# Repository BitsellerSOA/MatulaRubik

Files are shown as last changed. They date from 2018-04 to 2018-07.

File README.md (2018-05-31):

# MatulaRubik
Proyecto SOA UNLAM 2018 1 C Martes Noche

### Colaboradores
- [Radice Adrian](https://github.com/adrianRadice)
- [Sanabria Facundo](https://github.com/FockaSanabria)

### Introduccion
El proyecto es una implementación de IOT, el mismo consiste en un SE que tendrá el fin de resolver el cubo rubik. 

### Objetivo
Resolver el cubo rubik, mediante un sistema automático.

### Limite
Desde que el cubo es analizado por la App Movil y el SE devuelve el cubo resuelto como fue indicado por la APP.

### Alcance
- La App Android `MatulaRubik` analizara el cubo, capturando la posición de los colores con el uso de la libreria OpenCV 3.4.1, y entregara en un repositorio web la solución a ser tratada por el SE.
- La App Android `MatulaRubik` registra un historial de logros ( Tiempos previos logrados ) y configuración del Cubo.
- El sketch de Arduino retirara la solución entregada por `MatulaRubik` del repositorio WEB.
- El sketch de Arduino interpretará  la solución  del cubo y la traducirá  en los movimientos mecánicos.

### Dedicación
Este proyecto es una dedicación especial a nuestro hermano perdido en acción. Matias por siempre presente en Bitseller.
<p align="center">
  
  
  
</p>

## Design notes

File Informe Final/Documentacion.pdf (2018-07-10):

# MatulaRubik

Nombre y Apellido Radice Adrián – Sanabria Facundo Asignatura Sistemas Operativos Avanzado – Docentes: Lic. De Luca Graciela – Ing. García Gerardo – Ing. Valente Waldo – Ing. Carnuccio Esteban.
Universidad Nacional de La Matanza – Departamento de Ingeniería e Investigaciones Tecnológicas (http://ingenieria.unlam.edu.ar/index.php?seccion=4)

radiceadriann@gmail.com - facundosanabria@gmail.com

Kerwords IOT – Rubik – Arduino – Ethernet – Android – JSON – Post – Steeper – Driver – Puente H – DRV8825 – L293 – NDK – OpenCV.

Abstract- El objetivo del presente trabajo es desarrollar
un sistema de IOT, donde se demuestra el conocimiento adquirido en la cátedra de sistemas operativos avanzados. El propósito del sistema es Resolver el conocido juego de lógica Cubo Rubik 3x3x3, automáticamente.
Podrán tener acceso al código y detalles de construcción en el repositorio [github.com/BitsellerSOA/MatulaRubik].
I. INTRODUCCIÓN

El presente trabajo es una implementación de IOT, el mismo consiste en un SE que tendrá el fin de resolver el cubo Rubik de 3x3x3. El cubo Rubik es un juego que combina lógica con movimientos mecánicos. Existen diversos algoritmos para resolverlo. El elegido en el presente trabajo es el algoritmo CFOP (Cross – F2L – OLL – PLL) o también conocido por el nombre de su autor Fridrich. El algoritmo será aplicado por un equipo celular con Sistema Operativo Android, el cual entregará la secuencia de movimientos a aplicar por la parte mecánica del sistema controlada por un Arduino Mega 2560.

II. OBJETIVO

Resolver el cubo Rubik 3x3x3, mediante un sistema automático implementando IOT.

III. LIMITE

Desde que el cubo Rubik de 3x3x3 es analizado por la App Móvil y el SE devuelve el cubo resuelto como fue indicado por la APP.

IV. ALCANCE

- La App Android MatulaRubik analizara el cubo, capturando la posición de los colores con el uso de la librería OpenCV 3.4.1, y entregara en un repositorio web la solución a ser tratada por el SE.
- La App Android MatulaRubik registra un historial de logros (Tiempos previos logrados) y configuración del Cubo.
- El sketch de Arduino retirara la solución entregada por MatulaRubik del repositorio WEB.
- El sketch de Arduino interpretará la solución del cubo y la traducirá en los movimientos mecánicos.
- El sistema embebido ante desconexión, o reseteo volverá al estado de reposo, no necesariamente informando a la app.
V. SOFTWARE UTILIZADO
- Android Studio. Para el desarrollo de la app Android.
- Arduino IDE 1.8.5. Para el desarrollo del sketch Arduino.
- Enterprise Architect. Para diagramas y documentación.
- Git. Para el control de versiones del código.
- Fritzing. Para Los diagramas de circuitos.
VI. | HARDWARE UTILIZADO
ELECTRONICA | CANTIDAD
Arduino Mega 2560 | 1
Capacitor 1000uf | 1
Capacitor 100uf | 3
DRV 8825 | 3
L293D | 1
Motor DC | 1
Shield W5100 | 1
Stepper | 3
Fin de carrera | 1
Resistencia
OTROS | CANTIDAD
Cable
Perfboard | 1
Zocalos | 1
VII. | MATERIALES UTILIZADOS
VIII. | HERRAMIENTAS UTILIZADAS
- Soldador.
- Taladro.
- Mecha Madera y Metal
- Destornillador.
- Multímetro.
- Alicate.

IX. DETALLES COMPONENTES

ARDUINO MEGA 2560

Objetivo en el proyecto: Se encargará de efectuar los movimientos mecánicos que implican resolver el Puzzle.

MATERIAL | CANTIDAD | DIMENSION
Acrílico | -
Aluminio | -
Varilla Enroscada | 4
Chapa Galvanizada | -
Estaño | -
Madera | -
Pegamento | -
Tornillo (Pinzas) | 3
Tornillo (Sujeta retroceso) | 4
Tornillo (Sujeta Steeper) | 12
Tuerca | 16

Características:

CARACTERISTICAS ELECTRICAS
Microcontrolador | ATmega 2560
Tensión de operación | 5V
Tensión de alimentación | 6-20V recomendado 7-12V
Pines digitales | 54 (15 proveen salida PWM)
Pines Analógicos | 16
Corriente por Pin I/O | 20mA
Corriente Pin salida 3.3V | 50mA
Memoria Flash | 256KB – 8KB Bootloader
Clock | 16 MHz
DIMENSIONES
Largo | 101.52 mm
Ancho | 53.3 mm

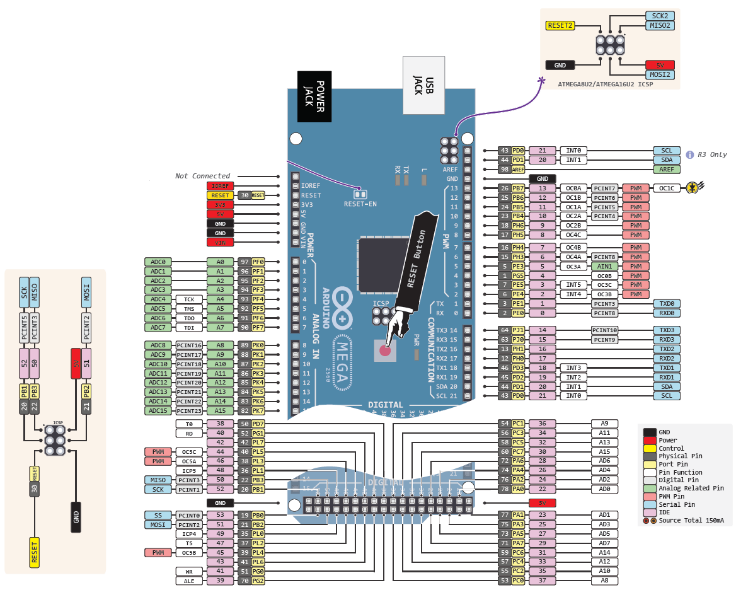
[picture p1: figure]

Fig. 1. Mapa de pines Arduino.

SHIELD W5100

Objetivo en el proyecto: permite la comunicación entre el Arduino y el celular. No se usa del shield las prestaciones para SD.

Pin Arduino: 50 – 51 – 52 – 53 para la comunicación SPI.

Características

- Tensión de alimentación: utiliza 5V suministrados por el Arduino.
- Buffer interno de 16k.
- Permite comunicaciones 10/100Mb.
- Indicadores Led
- TX
- RX
- LINK
- 100M
- ON

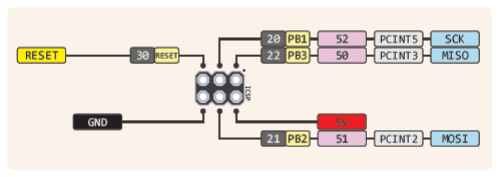
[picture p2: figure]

Fig. 2. Diagrama que indica que los pines del 50-53 están imposibilitados para su uso.

FIN DE CARRERA

Objetivo en el proyecto: indicar cuando el motor DC alcanzo la posición deseada.

Configuración: NC con resistencia Pull Down.

Señal: Digital.

Estados: High cerrado, Low Abierto. Por configuración NC.

Pin Arduino: Pin 22 configurado como entrada.

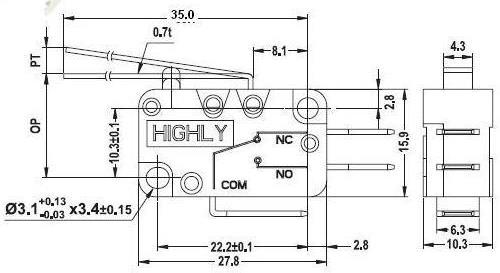
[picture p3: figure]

Fig. 3. Diagrama físico del sensor fin de carrera.

Iteración con Arduino: Para simplificar su descripción utilizaremos el autómata descripto en la Fig 1.

- El estado 1 implica el Motor DC en reposo.
- El estado 2 indica el motor DC excitado.
- La transición q1 se da cuando el Arduino interactúa con el puente H y este polariza el motor DC para que empiece a moverse.
- La transición q3 implica la lectura Low en el pin digital en el que está conectado el fin de carrera.
- La transición q2 implica la lectura HIGH en el pin digital en el que está conectado el fin de carrera.

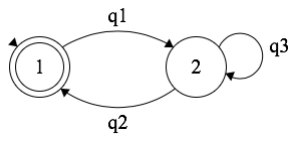
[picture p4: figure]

Fig. 4. Máquina de estados iteración Arduino fin de carrera.

Iteración Mecánica: Dado que existen retardos para pasar del estado 2 al 1, la chapa del fin de carrera respecto a la posición deseada se separa una distancia D Fig 1. Los retardos incluyen desde que se recibe el nivel alto en el Arduino, este envía la orden de detención, el DC se detiene y se compensa el empuje.

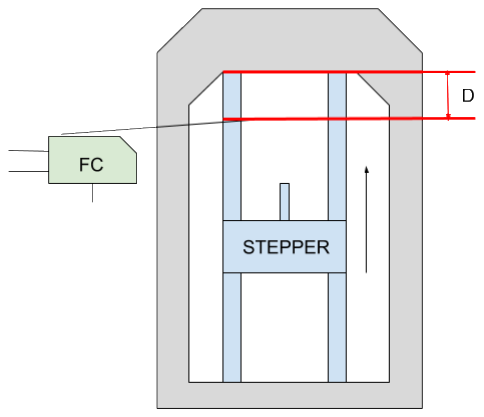
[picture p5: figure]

Fig. 5. Representación física de la iteración. No está a escala.

RESISTENCIA

Objetivo en el proyecto: Completar circuito para el Fin de carrera. La misma permite que no se produzca un corto al cerrarse el circuito.

Valor: 10kΩ

Estados: High cerrado, Low Abierto. Por configuración NC.

Fig. 6. Diagrama lógico de configuración pull down.

CAPACITOR

Objetivo en el proyecto: Proteger a los DRV8825 que son muy sensibles a picos de tensión. Estas variaciones de tensión principalmente aparecen cuando los motores actúan.

Tipo: Electrolítico.

Valores: el fabricante del drv8825 recomienda capacitores con un valor mínimo de 47uf, dado a nuestra disponibilidad usamos de 100uf.

PERFBOARD

Objetivo en el proyecto: permite el montaje de los circuitos comentados en FIG 15. La perfboard es una placa de circuito perforada cuyos huecos están circundados por material conductor, usualmente cobre, pero que no están interconectados entre sí. Este tipo de placas requieren que cada componente esté soldado a la placa y además las interconexiones entre ellos sea realizada a través de cables o caminos de soldadura.

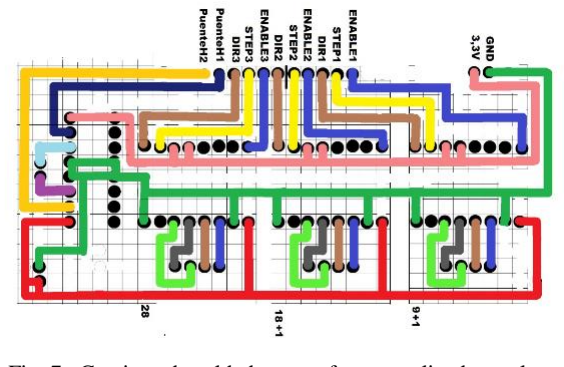
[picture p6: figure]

Fig. 7. Caminos de soldadura que fueron realizados en la perfboard.

CABLE SIMPLE

Objetivo en el proyecto: conductores eléctricos. Se utilizan para interconectar los motores al driver, y en la alimentación del sistema embebido.

1 Para el proyecto no es necesario un puente H doble, se utilizó el L293D porque ya se lo poseía.

CABLE ETHERNET

Objetivo en el proyecto: Permite la conexión del SE a una Red.

Características: UTP CAT 5e Norma T568, Cruzado.

MOTOR DC

Objetivo en el proyecto: el retroceso y avance del brazo que mueve la cara lateral.

Características: Tención de alimentación 9V.

Sentido de giro: Controlado por el puente HL293D.

PUENTE H L293D¹

Objetivo en el proyecto: Control de giro del Motor DC que desplaza el brazo lateral.

Características:

CARACTERISTICAS ELECTRICAS
Tensión lógica | 5V
Tensión de salida (Usada) | 9V
Corriente de salida | 600 mA
Admite PWM | SI

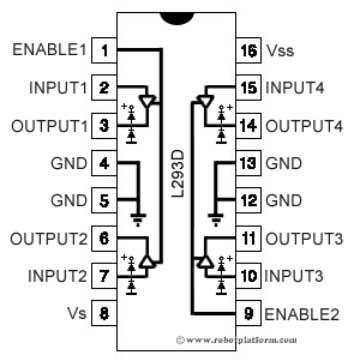
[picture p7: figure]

Fig. 8. Pines Integrado L293D

Pin Arduino: Pin 38 y 39 configurado como salida.

Iteración con Arduino:

ENABLE | INPUT 1 | INPUT 2 | Motor
LOW | HIGH/LOW | HIGH/LOW | PARADO
HIGH | HIHG | LOW | MOV 1
HIGH | LOW | HIGH | MOV 2

Tab. 1. En el proyecto solo se trabaja con las dos últimas filas. Mov 1 y Mov 2 representaran en el proyecto un movimiento de izq a derecha o de derecha a izquierda.

MOTOR STEPPER BIPOLAR

Objetivo en el proyecto: se encarga de rotar las caras del cubo con pasos de π/2 y múltiplos del mismo.

Características:

CARACTERISTICAS ELECTRICAS
Step Angle | 1.8 deg (200 pas por vuelta)
Tensión | 4,83 V
Corriente | 0.84 A
Torque | 2.8 Kg/cm

Movimiento: Controlado por el DRV8825.

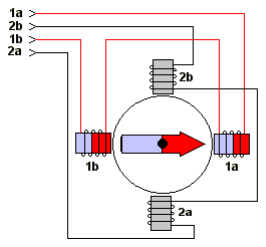
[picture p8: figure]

Fig. 9. Esquema de un motor bipolar. Se denominan bipolares porque de acuerdo al sentido de la corriente se forma un campo magnético S/N o N/S.

Fig. 10. Dimensiones físicas del motor utilizado.

DRV8825

Objetivo en el proyecto: Control de los motores paso a paso del circuito. En sencillas palabras actúan como una válvula que separa la corriente que alimenta al Arduino de la que es necesario hacer circular por el motor. Este driver particularmente esta compuesto por dos puente H que utiliza para cambiar la dirección de la corriente en las bobinas del motor bipolar que controla.

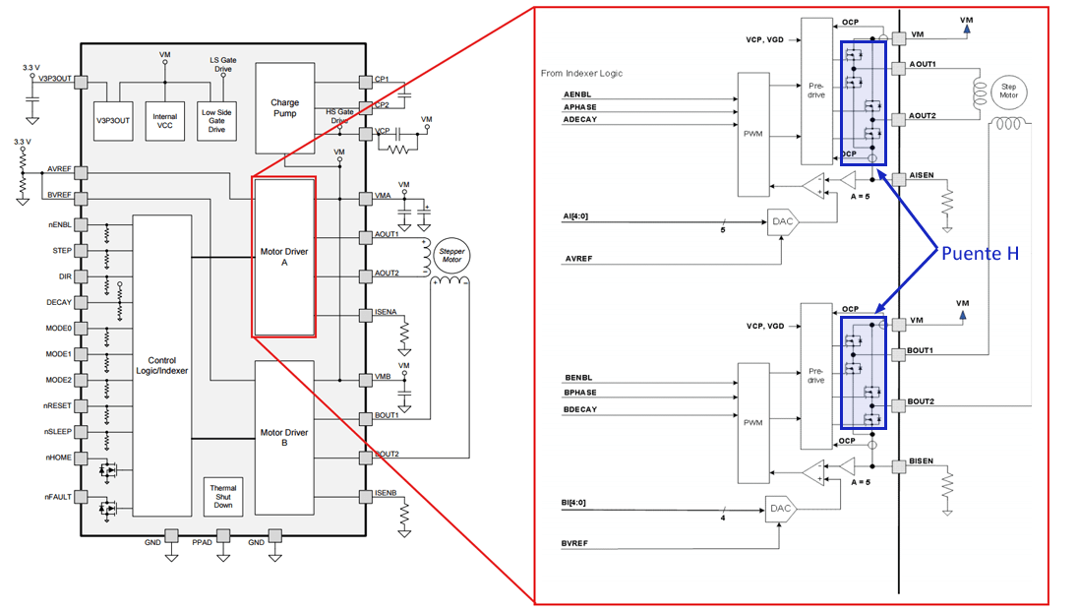
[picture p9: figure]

Fig. 11. Composición del DRV8825.

Características:

CARACTERISTICAS ELECTRICAS
Intensidad máxima | 2.5A a 24V
Tensión máxima | 8.2V a 45V
Tensión de pines lógicos de entrada | 2.25V a 5.5V

Pin Arduino: Pines 24, 28, 33 para enable, 25,30 y 34 para step y 26, 31 y 36 para dirección.

Iteración con Arduino:

El Arduino envía el pulso (STEP). Cada pulso le dice al motor que tiene que avanzar un paso. Otro pin nos dice la dirección de avance (DIR). Si queremos ir en el sentido de las agujas del reloj, o al contrario. De esta forma, cada vez que el driver recibe un pulso en el pin STEP, el circuito comprueba el voltaje del pin DIR, y alimenta las bobinas del motor en el orden adecuado.

Fig. 12. Señal enviadas al Driver.

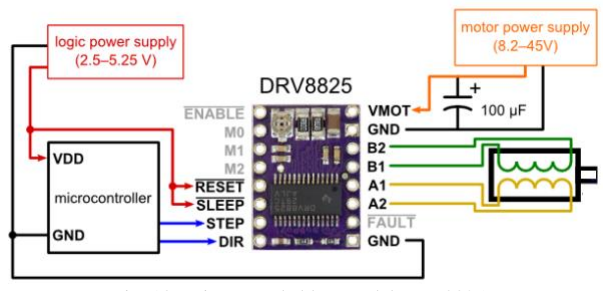
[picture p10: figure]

Fig. 13. Diagrama de bloques del DRV8825.

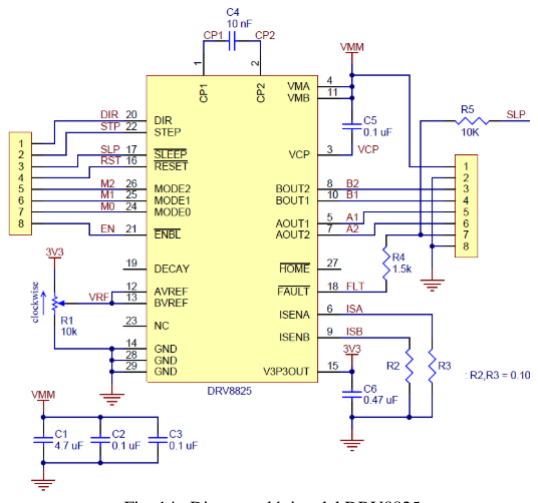
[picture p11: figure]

Fig. 14. Diagrama lógico del DRV8825

X. CIRCUITOS

CIRCUITO PARA CONTROL DE MOTOR STEPPER.

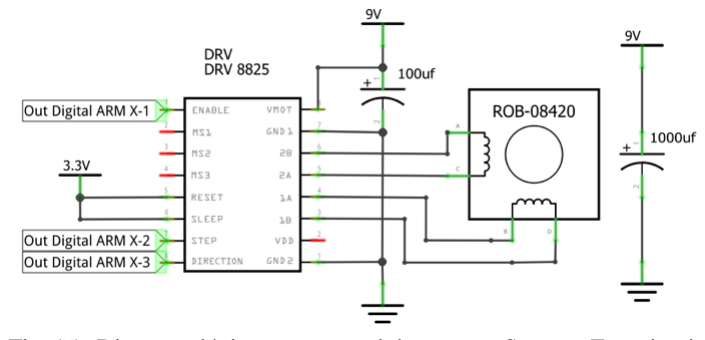
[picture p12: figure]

Fig. 15. Diagrama lógico para control de motores Stepper. Este circuito se implementa 3 veces para controlar cada uno de los motores. El circuito completo podrá ser consultado al final de este documento.

Etiqueta | Pin Arduino
MOTOR U
X-1 | 24
X-2 | 25
X-3 | 26
MOTOR D
X-1 | 28
X-2 | 30
X-3 | 31
MOTOR L
X-1 | 33
X-2 | 35
X-3 | 36

BREVE EXPLICACIÓN DEL CIRCUITO:

El objetivo de este circuito es el control de un motor paso a paso, por lo tanto, tendremos 3 en total. Los motores pasos a paso tienen como objetivo principal efectuar los movimientos sobre las caras del cubo. Los movimientos a efectuar son giros de 90 grados en sentido horario/antihorario o múltiplos del mismo. El DRV será el intermediario entre el paso a paso y el Arduino. El capacitor de 100uf observador en la figura fue recomendado por el fabricante como fue especificado en el apartado Detalles de componentes Capacitor.

CIRCUITO PARA CONTROL DE MOTOR DC.

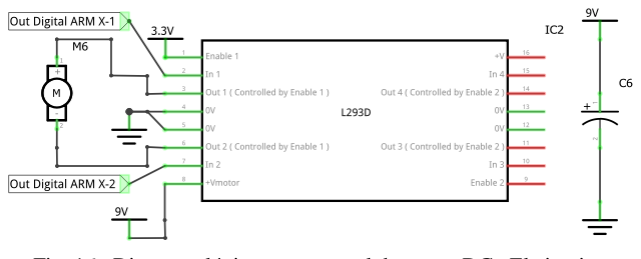
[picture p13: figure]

Fig. 16. Diagrama lógico para control de motor DC. El circuito completo podrá ser consultado al final de este documento.

Etiqueta | Pin Arduino
MOTOR DC
X-1 | 52
X-2 | 53

BREVE EXPLICACIÓN DEL CIRCUITO:

El objetivo de este circuito es permitir un desplazamiento horizontal de uno de los brazos. Un movimiento horizontal puede ser de izquierda a derecha o de derecha a izquierda. Para lograr dicho movimiento, si el objeto que queremos mover interactúa con un tornillo sin fin, bastaría con cambiar el sentido de giro de un motor. El motor que interactúa en esta parte del circuito es un DC convencional, por lo tanto, su sentido de giro queda determinado por cómo es polarizado. Para paralizar de dos formas distintas al motor utilizamos un puente H, en este caso uno de los dos que provee el L293D. Los 3.3v que son utilizados para habilitar el L293D serán suministrados por el Arduino. Los 9v empleados para alimentar el motor DC serán suministrados por la fuente externa que alimenta a todo el proyecto. X-1 y X-2 enviaran los pulsos necesarios para lograr la codificación digital (Tab. 1) que requiere el puente H.

XI. CONSTRUCCIÓN MECÁNICA

MAQUINA:

PONER UNA FOTO CON LA ESTRUCTURA ARMADA Y PONER CON PAINT UNA ETIQUETA SOBRE LOS MOTORES E INDICAR QUE CARAS MUEVEN CADA UNO, Y PUNTO.

Motores | Movimiento
MS-U | U
MS-D | D
MS-L | { F, L , R , B }
M-DC | RETROCESO M-L
{U, D, F, L, R, B} Son las caras del cubo Rubik, en introducción sobre CFOP se explica la nomenclatura.

PINZAS:

Para sujetar las pinzas a los ejes del motor paso a paso, se utilizó el concepto de las borneras.

Fig. 16. En azul se simboliza al tornillo que presionara el borde plano del eje del motor paso a paso.

PINZAS SUPERIOR E INFERIOR:

PINZA LATERAL:

XII. INTRODUCCIÓN A CFOP

Existen muchos algoritmos para poder resolver el cubo Rubik, en este trabajo se eligió a CFOP o también conocido por el nombre de su autor Fridrich. El motivo fue porque era el que conocíamos. El algoritmo como indica en su sigla se compone de 4 etapas Cross, F2L, OLL, PLL.

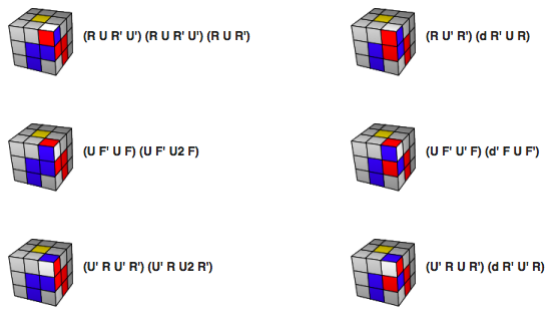
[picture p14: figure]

Fig. 18. Automta que representa las etapas principales del Algoritmo

El algoritmo tiene una nomenclatura especifica la cual fue adoptada para nuestro proyecto con ciertas modificaciones.

CARAS (C)
Superior (Up) | U
Inferior (Down) | D
Trasera (Back) | B
Derecha (Right) | R
Izquierda (Left) | L
FRONTAL (Front) | F
Movimientos
Horario 90* | (C)
Horario 180* | (C)2
Antihorario 90* | (C)’
Antihorario 180* | (C)’2

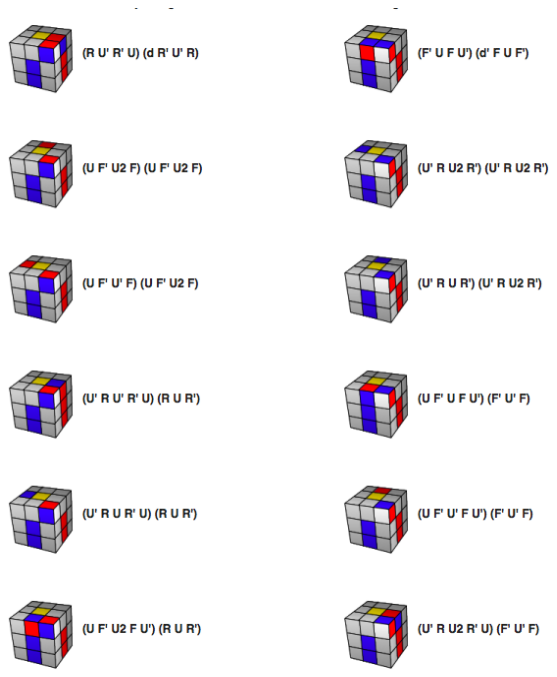
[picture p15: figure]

Fig. 19. Nomenclatura. Notar que en la nomenclatura se emplea un apostrofe para los movimientos antihorarios, que en el código será remplazado por una ‘A’ quedando por ejemplo FA, UA, etc. Se considera sentido horario respecto a mirar la cara de frente. Los movimientos de 180 grados fueron efectuados como dos consecutivos de 90 grados.

Para el desarrollo del paper, consideramos que empezamos armando la cara blanca. A continuación se detalla cada uno de los estados de las distintas etapas, y la secuencia de movimientos que implican cambiar de estado.

CROSS

Objetivo: Armar cruz en la cara de partida.

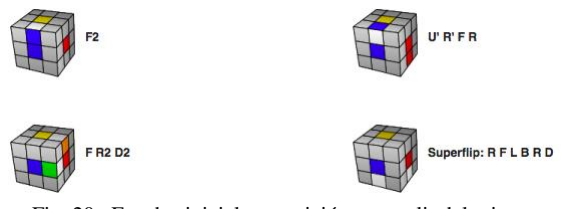
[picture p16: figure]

Fig. 20. Estados inicial y transición para salir del mismo.

F2L FIRST TWO LAYER

Objetivo: Ubicar esquinas de cara inferior, y bordes de cara intermedia. Se pueden dar 41 casos.

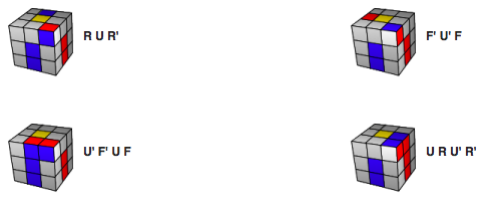
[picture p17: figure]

Fig. 21. Estados inicial y transición para salir del mismo.

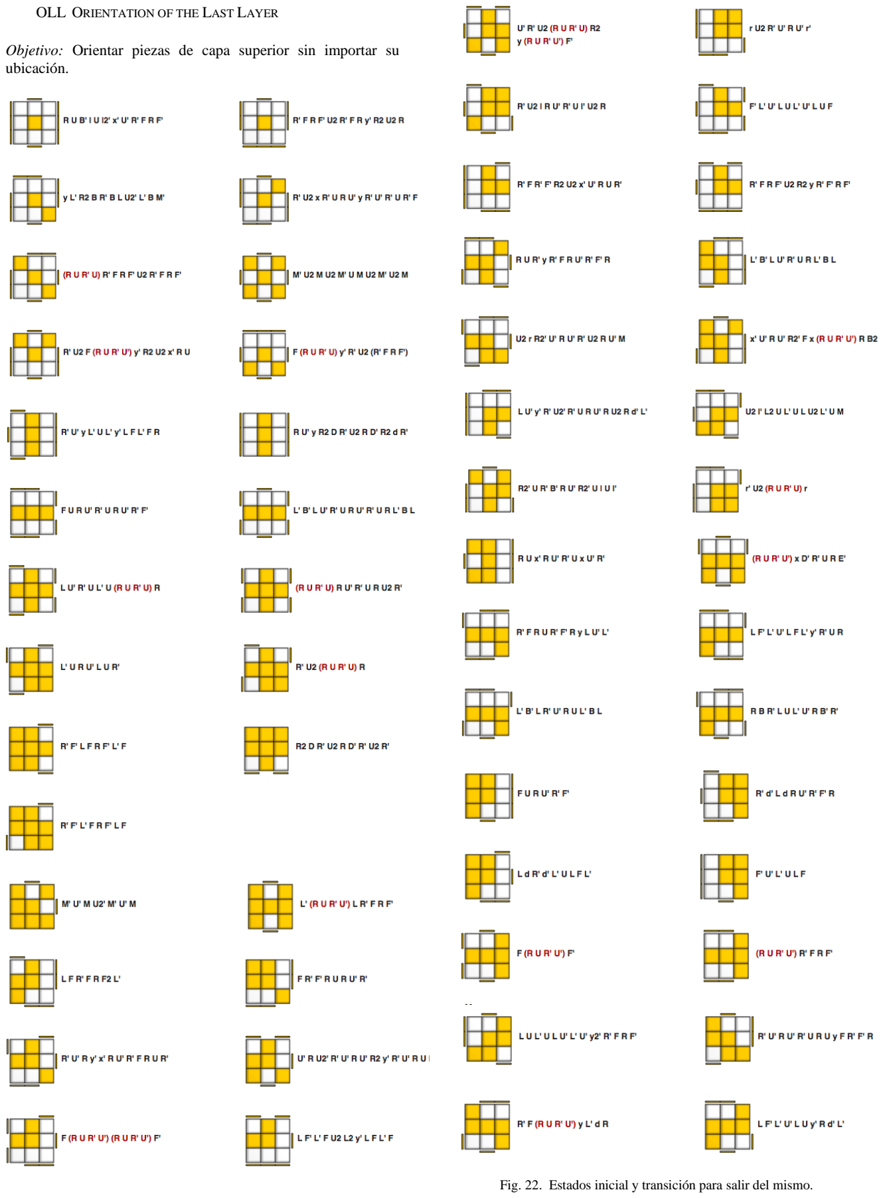
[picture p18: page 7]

OLL ORIENTATION OF THE LAST LAYER

Objetivo: Orientar piezas de capa superior sin importar su ubicación.

Fig. 22. Estados inicial y transición para salir del mismo.

PLL PERMUTATION OF THE LAST LAYER

Objetivo: Ubica en la posición correcta las piezas de la capa superior.

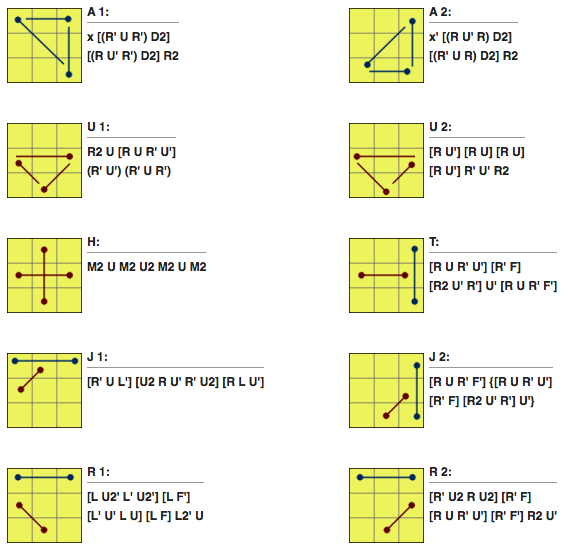
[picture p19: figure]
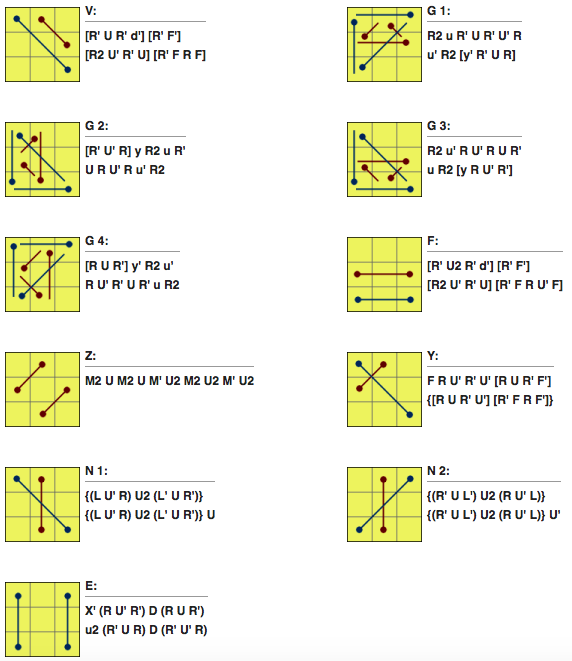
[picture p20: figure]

Fig. 23. Estados inicial y transición para salir del mismo.

ALMACENAMIENTO DEL CUBO

La ubicación de las artistas y esquinas del cubo se almacenan en una matriz de 6*9 del tipo char. Con la siguiente distribución.

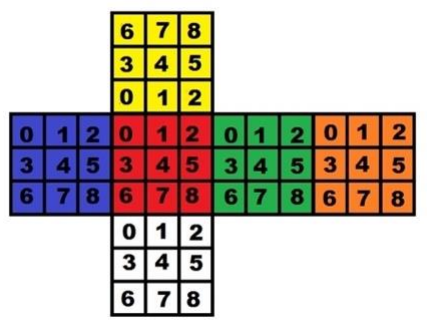
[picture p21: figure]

Fig. 24. Estados inicial y transición para salir del mismo.

XIII. COMUNICACIÓN APP Y ARDUINO

RESUMEN MENSAJES JSON INTERCAMBIADOS

- OK
- ERROR
- DESCONEXION
- SOLUCION LISTA
- COLOCAR CUBO
- {R, L, D, U, B, F, X, Y, Z, V, W, N} REPRESENTAN
MOVIMIENTOS.

PSEUDOCODIGO

1 La App verifica si existe el Arduino.
1.1 La App envía un mensaje a la Dirección IP del Arduino.
1.2. La app Espera respuesta del Arduino por un intervalo de tiempo determinado.
1.3. El Arduino ante la solicitud del celular puede:
1.3.a No responder.
1.3.a.1 Se vence el plazo de tiempo en la app y emite un mensaje que dice Arduino no responde.
1.3.b Estoy Ocupado
1.3.b.1 La app informa el estado del Arduino.
1.3.c Estoy disponible
2 Si La app determina la disponibilidad del Arduino, verifica tener el cubo frente a su cámara.
2.1 Si la respuesta anterior es negativa solicita que se coloque un cubo.
2.2 Si la respuesta anterior es positiva escanea la primera cara. 2.3 La app Envía un post a Arduino indicando que mueva el motor de abajo y superior en sentido horario.
2.4 Arduino ejecuta el movimiento y informa a la app.
2.5 La app escanea la cara.
SE REPITE 3 VECES LA SECUENCIA DEL 2.4 AL 2.5
3 La app notifica que se mueva el motor lateral mediante un post para escanear la cara inf.
3.1 Arduino recibe la solicitud ejecuta la combinación de movimiento motor lateral y luego inferior y superior para que la cara inferior quede frente la cámara
3.1 La app escanea la cara
La app notifica que se mueva el motor inf y sup para que la cara sus quede frente a la cámara
4.1 Arduino recibe la solicitud ejecuta el movimiento
4.2 La app escanea la cara
La app Aplica el algoritmo para resolver, mientras tanto Arduino espera el post de la app indicando la disponibilidad de la solución para poder descargarla y aplicarla.
La app espera que Arduino indique que termino de aplicar la secuencia de movimientos y notifica a la aplicación que finalizo. APARTIR DE PASO 5 NO ES NECESARIO EL CELULAR EN LA BASE DE LA MAQUINA

XIV. DIAGRAMAS APP
- Activity
- Acerca => Información de la aplicación
- Apertura => Splash de bienvenida
- Main => principal
- Clases
- CFOP => Algoritmo de resolución
- ColorDectector => Reúne métodos para detectar lo colores con la cámara.

- Solver => Reúne los métodos para resolver el cubo

XV. REQUISITOS APP

Requisito
OS | > = Android 6.0
Cámara | SI
Uso de Red | SI
Memoria | <COMPLETAR>
XVI. | INTRODUCCIÓN A OPENCV Y NDK

OPENCV es una librería de visión artificial de uso libre, desarrollada en C/C++ lo cual para poder ser utilizada por Android debemos recurrir a la cross compilación ofrecida por NDK. De los módulos ofrecidos por OPENCV emplearemos el CORE ( Incluye las estructuras de datos básicas y las funciones básicas de procesamiento de imágenes) y el OBJDETECT.

Para la detección de colores utilizaremos el concepto de máscaras y el espacio de colores HSV. Cada mascará definirá un rango de valores máximo y mínimo. Tendremos una máscara por color excepto por el rojo que dado a la ubicación del mismo en el campo de HSV requiere dos, porque tiene dos rangos Fig.5.

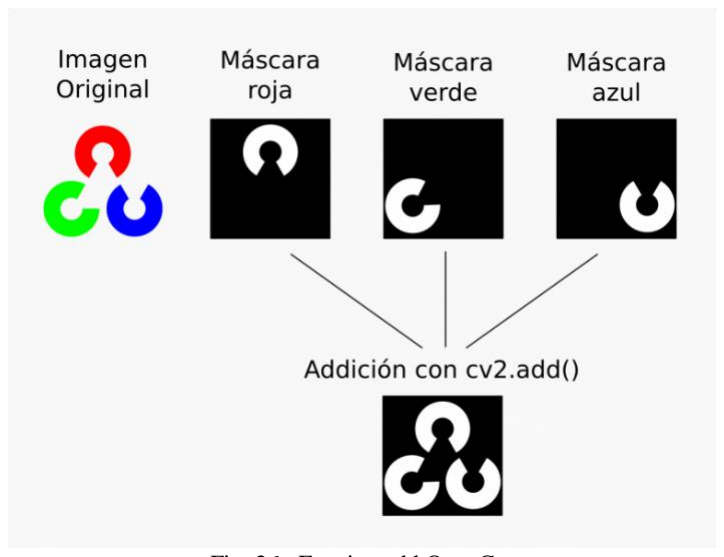
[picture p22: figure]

Fig. 26. Funcion add OpenCv.

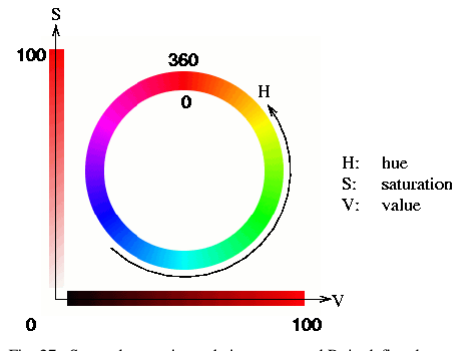
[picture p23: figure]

Fig. 27. Se puede apreciar en la imagen que el Rojo define dos rangos por la componente H, uno del 0 hasta estar próximo al amarillo, y otro desde las fronteras con el violeta hasta el 0.

XVII. IMPLEMENTANDO HPC

Consultar
https://github.com/BitsellerSOA/MatulaRubik/tree/master/TP%20HPC/HPC.pdf

XVIII. PRUEBAS

PRUEBAS ALGORITMO DE RESOLUCIÓN

Dado que son extremadamente grandes (eq.1) todas las configuraciones que se pueden obtener al mezclar el cubo Rubik, sería imposible querer probar que el algoritmo puede resolverlas a todas. Por lo tanto, consideraremos que resolver el cubo seria la integración de muchos métodos, que podrán ser probados unitariamente y luego mediante una prueba de integración podremos afirmar que si logra resolver 10 escenarios distinto el algoritmo será aceptable.

Las pruebas unitarias que deberá enfrentar el algoritmo podrán ser agrupadas en 3 etapas a ejecutar en orden:

- Realiza los movimientos simples correctamente.
- Resuelve correctamente un paso del algoritmo CFOP.
- | Identifica | correctamente | que | secuencia | de
movimientos se debe aplicar.

La primera etapa es fácil de probar, el objetivo es que haga los desplazamientos correctamente en la matriz. Por lo tanto se tendrá una prueba para cada posible movimiento del cubo { U, U’, D, D’, L, L’, R, R’, B, B’, F, F’}. Se partirá siempre del cubo ordenado (matriz Fig. 5) y se comparará con el resultado esperado.

La segunda etapa tiene como objetivo probar a cada una de las secuencias de CFOP. Se entrega la matriz en el estado esperado y luego se compara con la matriz obtenida, para identificar si la secuencia es correcta.

La tercera etapa, probara el método que determina en qué estado se encuentra el cubo, para ello se entrega el cubo desordenado y se compara con el estado esperado.

Superada las tres etapas anteriores consideramos que el algoritmo será óptimo para pasar a la prueba de integración. Donde se entregará 10 configuraciones distintas del cubo con distintos grados de complejidad, y se probará que la matriz quede en el estado de cubo resuelto.

PRUEBAS IDENTIFICACIÓN DE COLORES

Dada las características de esta operación, esta prueba no puede ser automatizada, por lo tanto, se realizará por inspección visual. Se entregan por lo menos 10 distintas configuraciones random del cubo y se observa que los colores sean correctamente identificados por la aplicación. Los colores mostrados por la app deberán coincidir con los reales.

PRUEBAS INSPECCIÓN DE COLORES

Dada las características de esta operación, esta prueba no puede ser automatizada, por lo tanto, se realizará por inspección visual. El objetivo de esta prueba es la correcta sincronización entre la app y el Arduino. Se probará que el intercambio de confirmaciones entre ambos, en donde ni la app deberá inspeccionar colores hasta que Arduino se lo confirme, así como el Arduino no efectué movimientos hasta que la app se lo indique.

PRUEBAS DESCONEXIÓN DURANTE INSPECCIÓN

Dada las características de esta operación, esta prueba no puede ser automatizada, por lo tanto, se realizará por inspección visual. El objetivo de esta prueba es la correcta sincronización entre la app y el Arduino. Ante la pérdida de comunicación entre la app y el Arduino, la app deberá informar por pantalla, y el Arduino quedará en estado de reposo. La pérdida de comunicación se evaluará de la siguiente forma.

- Desconexión del Arduino durante la inspección.
- Reseteo del Arduino durante la inspección.
- Cierre de la app durante la inspección.
- Desconexión del celular de la red.

PRUEBAS MOVIMIENTO ARDUINO

Desconocemos técnicas de pruebas automatizadas para hardware, por lo tanto, usaremos la inspección visual. Se entregará al SE el cubo y se probará cada una de las funciones del sketch que representa un movimiento, si lo aplica correctamente. Las funciones a probar son:

- | u() | • | uA() | • | mover(char c)
- | d() | • | dA()
- | f() | • | fA()
- | r() | • | rA()
- | l() | • | lA()
- | b() | • | bA()

PRUEBAS JSON ARDUINO

Se probará que se realice correctamente el parcing, es decir se envía un paquete desde la app, se la recibe con el Arduino y mediante la impresión por puerto serial se observa si es capaz de obtener el movimiento solicitado, o la orden de continuar o cualquiera de los mensajes que previamente definimos.

XIX. ANEXO CÁLCULOS

Cant config =

8!∗3

8
∗12!∗2

12
12

(eq.1)

XX. AUTORES

Radice AdrianArgentino, estudiante de ingeniería en informática en la Universidad Nacional de La Matanza.
Profesional dedicado a sistemas informaticos. Usr GitHub: adrianRadice

Sanabria FacundoArgentino, estudiante de ingeniería en informática en la Universidad Nacional de La Matanza.
Profesional dedicado a sistemas informaticos. Usr GitHub: FockaSanabria

CIRCUITO GENERAL

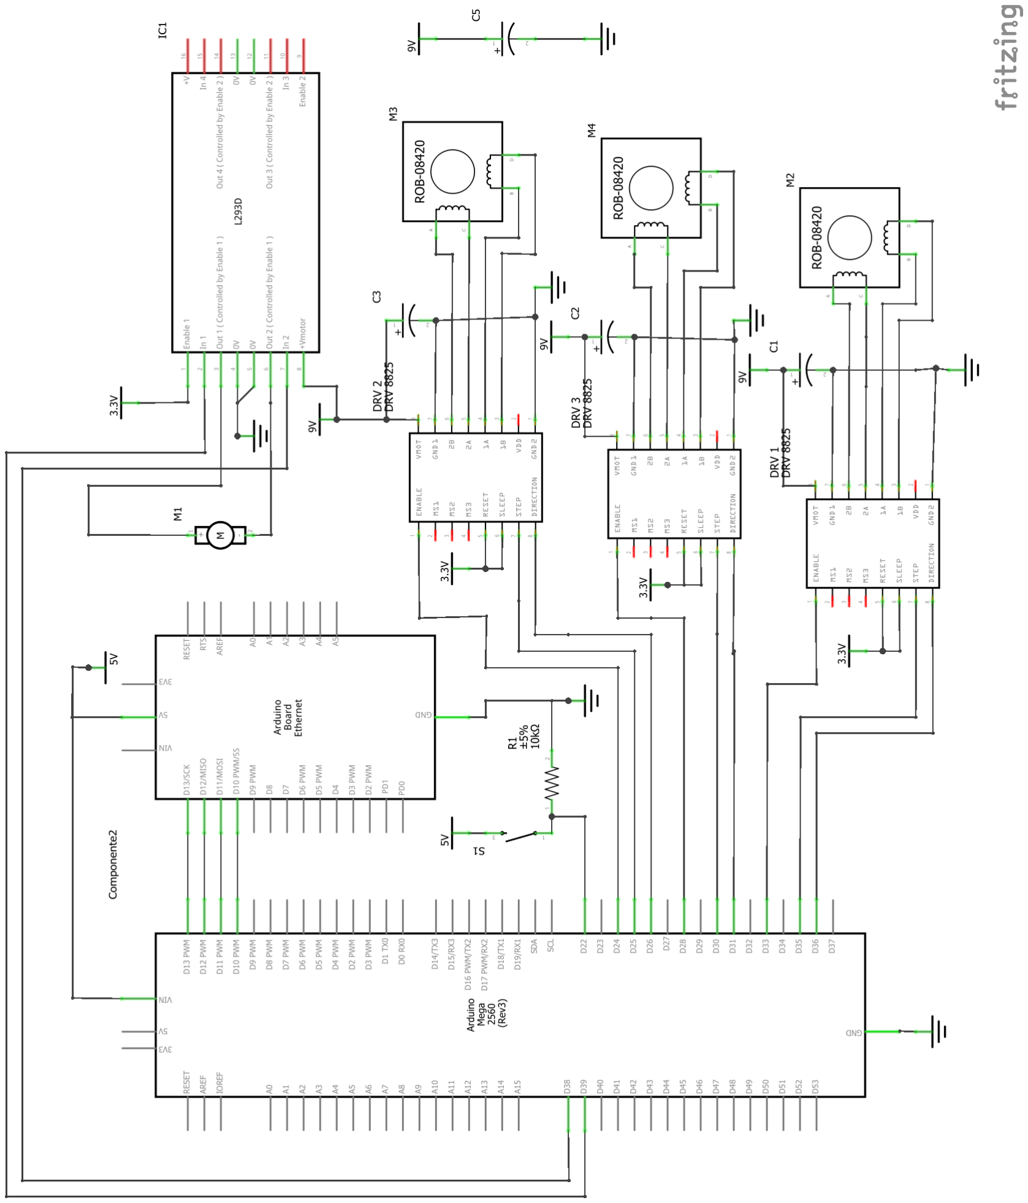
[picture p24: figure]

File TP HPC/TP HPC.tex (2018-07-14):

\documentclass[runningheads,a4paper]{llncs}

\usepackage{amssymb}
\setcounter{tocdepth}{3}
\usepackage{graphicx}

\usepackage{url}

\urldef{\mailsa}\path|{radiceadriann, facundosanabria}@gmail.com|    
\newcommand{\keywords}[1]{\par\addvspace\baselineskip
\noindent\keywordname\enspace\ignorespaces#1}

\newcommand{\MR}{$\emph{MatulaRubik}$ } 

\begin{document}

\mainmatter  % start of an individual contribution

% first the title is needed
\title{Trabajo de Investigación:\\
Integración de HPC en IOT}

% a short form should be given in case it is too long for the running head
\titlerunning{Investigación: HPC y Rubik}

% the name(s) of the author(s) follow(s) next
%
% NB: Chinese authors should write their first names(s) in front of
% their surnames. This ensures that the names appear correctly in
% the running heads and the author index.
%
\author{Adrian Radice%
\and Facundo Sanabria}
%
\authorrunning{Investigación: HPC y Rubik}
% (feature abused for this document to repeat the title also on left hand pages)

% the affiliations are given next; don't give your e-mail address
% unless you accept that it will be published
\institute{Universidad Nacional de La Matanza,\\ Departamento de ingeniería e Investigaciones Tecnológicas,\\
Florencio Varela 1903 - San Justo, Argentina\\
\mailsa\\
\url{http://www.github.com/BitesellerSOA}}

%
% NB: a more complex sample for affiliations and the mapping to the
% corresponding authors can be found in the file "llncs.dem"
% (search for the string "\mainmatter" where a contribution starts).
% "llncs.dem" accompanies the document class "llncs.cls".
%

\toctitle{Lecture Notes in Computer Science}
\tocauthor{Authors' Instructions}
\maketitle

\begin{abstract}
El objetivo del presente trabajo es investigar los beneficios de incorporar HPC en el proyecto de IOT
\MR. Dicho proyecto tiene como desafío resolver un problema NP. Este problema es el puzzle Rubik 3x3x3, el cual
se solucionara implementando el algoritmo no determinístico CFOP. CFOP varia de acuerdo cual 
se su cara de partida, por lo tanto para cualquier cubo se tienen 6 estados iniciales. El desafío es de 6 posibles caminos para 
llegar al estado final, quedarse con aquel que implique el menor uso del brazo lateral.
\keywords{HPC, IOT, Android, Rubik, Paralelismo, OpenCL}
\end{abstract}

\section{Introducción}
\MR es un SE con el objetivo de resolver el Cubo Rubik de 3x3x3, en una primera instancia aplicando el algoritmo utilizado para competencias de velocidad CFOP, el cual obtiene un promedio entre 50 y 100 movimientos para resolver cualquier cubo.
Este algoritmo pertenece a la familia de los llamados \emph{Layer by Layer}, y se caracteriza por llevar a cualquier configuración del cubo a un estado particular, reduciendo siempre 
al problema a la misma solución. En pocas palabras mezcla aun mas el cubo para llevarlo a estados conocidos. 
CFOP es un algoritmo en donde un estado tienen distintas transiciones que nos llevan al estado final, siendo 
cada una finalmente un camino con distinta o igual cantidad de movimientos. 

El objetivo de esta investigación, es reducir el tiempo en que \MR  entrega la solución. \MR  actualmente en su mecánica, 
tiene un retardo extra, la ubicación de las caras laterales en el correspondiente brazo para poder rotarlas. Se buscara mediante
la implementación de HPC con OpenCL, encontrar la solución que reduce el retardo previamente descrito.

\section{Desarrollo}

Estudiando la mecánica de \MR se aprecia que el efectuar movimientos en las caras L, F, R, B pueden sumar un retardo, que no existe nunca al trabajarse con las caras U y D. Por ejemplo la secuencia de movimientos F, B' implica, que luego de ejecutarse el primer movimiento, se sume un retardo temporal hasta que la cara B del cubo quede frente al brazo. Este retardo es el tiempo que implica retirar el brazo lateral, rotar el cubo hasta que B quede frente del brazo, y que el brazo lateral se ubique nuevamente en la posición de trabajo.

Enfrentar dicho problema implicaría dos caminos,  cambiar la mecánica, o buscar una reducción en los movimientos de las caras problemáticas. En el desarrollo del trabajo optaremos por el segundo camino.

\MR en su estado actual aplica el algoritmo CFOP, el mismo presenta la particularidad que para una misma configuración del cubo de acuerdo a la cara que se tome como punto de partida devolverá una secuencia de movimientos totalmente distinto. Es decir, es como si se rotase lógicamente el cubo respecto de uno de sus ejes, lo que provoca que todas las piezas cambien de posición y orientación, resultando en un estado desordenado distinto y por lo tanto el algoritmo devolverá un conjunto de movimientos completamente distinto.

Para lograr obtener la menor cantidad de movimientos posibles utilizando este algoritmo nos proponemos a ejecutar en forma paralela 6 hilos de CFOP, un hilo por cara del cubo.

En busca de no tener que modificar demasiado el código actualmente implementado, se busco una herramienta que implique una implementación sencilla y optima de paralelismo. La herramienta seleccionada fue Paralldroid.

Paralldroid es un framework de desarrollo, que tiene como objetivo facilitar el trabajo de los desarrolladores de aplicaciones móviles ejecutadas sobre sistemas operativos Android, de acuerdo a lo mencionado en "Performance Analysis of Paralldroid Generated Programs" \cite{jour}. El mismo añade un conjunto de anotaciones al lenguaje Java, basadas en las definidas por el estándar OpenCL, permitiendo al desarrollador usar un lenguaje de alto nivel, sin entrar en detalle de implementación de paralelismo, y delegandole la responsabilidad a Paralldroid de generar el programa paralelo, segun lo indicado en "ParallDroid: A Framework for Parallelism in Android" \cite{bookParalldroid}.
Paralldroid puede ser descargado como plugin para eclipse, y solo es necesario instalarlo para que comience a funcionar\cite{jour}.

\begin{figure}
\centering
        
        \caption{Resultado de la refactorización \cite{OpenCLbook}.}
\end{figure}

Como se puede apreciar en la Figura 1 este framework, mediante el código Java con anotaciones, obtendrá un código nativo OpenCL, invocado desde nuestras clases. Es elemental el uso de NDK en cualquier App para poder hacer uso de este framework.

\section{Distribución de operaciones}
La particularidad de los hilos de trabajos propuestos, es que son independíentes entre si, cada uno trabaja con su propia matriz de estado del cubo, sin intervenir con los otros. Partiendo de que el resultado de ParallDroid es una implementación de OpenCL \cite{jour}, cada hilo tendrá destinado un WorkGroup independíente. La primera ventaja de esta división, es que cada WorkGroup podrá ser ejecutado en una unidad de procesamiento distinta, si OpenCL lo considera \cite{OpenCLbook}, y como segunda ventaja es el escalado automático (asignación de WorkGroup a las unidades de procesamiento) que implementa OpenCL \cite{OpenCLbook}. Esta ultima ventaja hace referencia, a que un mismo código, en un dispositivo de mayor cantidad de unidades de procesamiento que WorkGroups, en el mejor de los casos cada  se asignara un WorkGroup por unidad de procesamiento, y en un dispositivo de menor cantidad,  OpenCL simplemente terminaría ejecutando un conjunto de los WorkGroups en serie, en las unidades de procesamiento disponible.

\section{Explicación Algoritmo}

Nos basamos en el típico ejemplo de paralelismo del producto entre un escalar y un vector. Buscar 6 soluciones es isomórfico a esto 
ultimo, si entendemos al resultado de la operación como un conjunto de 6 elementos. 

\medskip
\noindent
{\it Pseudocódigo}
\begin{verbatim}
@Parallel
public class SolverHPC_CFOP {
  private caras[];
  private  Solucion[];
 @Kernel
  private void Solver(CaraInicial){
         //CALCULAMOS LA SOLUCION
         Solucion [CaraInicial] <- CFOP(caraInicial);
  }
  private Solucion getBest(){
 	//SE CALCULA LA MEJOR SOLUCION
 	return Solucion[bestSol];
  }
}
public class Solver{
   SendSol(){
   	SendArduino(SolverHPC_CFOP.getBest());
   }
}
\end{verbatim}
%
\noindent

Según lo mencionado en "Performance Analysis of Paralldroid Generated Programs" \cite{jour}, ParallelDroid al refactorizar el código, agregaría el manejo de hilos, y nos abstrae de su desarrollo.

\section{Pruebas que pueden realizarse}
Para probar el rendimiento se propone, el desarrollo de un programa probador que mida el tiempo que le implica resolver 50 estados desordenados distintos del  puzzle a a MatulaRubik con HPC y luego sin HPC. A partir de estos resultados debería realizarse el promedio para ambos casos y comparar cual obtiene el mejor tiempo.

También seria útil comprobar que el conjunto de movimientos resultados sean distintos dependiendo por que cara se comienza y si difieren mucho entre ellos.

\section{Conclusión}

La fortaleza de la solución propuesta en la investigación, es que permite una implementación de paralelismo sin demasiado esfuerzo de desarrollo. Se aprovecha el poder computacional provisto por el Hardware de los dispositivos móviles, para contrarrestar una deficiencia mecánica. 

Extender la propuesta a cada uno de los distintos estados de CFOP en lugar de solamente los 6 iniciales seria computacionalmente intratable dado que CFOP es un algoritmo no determinístico, con una excesiva cantidad de estados posibles. Se compensaría los retrasos impuestos por la mecánica, con el tiempo de la búsqueda de mejor solución. 

\begin{thebibliography}{4}
\bibitem{jour} A. Acosta and F. Almeida, "Performance Analysis of Paralldroid Generated Programs" 2014 22nd Euromicro International Conference on Parallel, Distributed, and Network-Based Processing, Torino, 2014, pp. 60-67.
\bibitem{bookParalldroid} Vicente Blanco, "ParallDroid: A Framework for Parallelism in Android".
\bibitem{OpenCLbook} Aaftab Munshi, "The OpenCL Specification" Khronos OpenCL Working Group, Revision 2015.
 \end{thebibliography}
\end{document}

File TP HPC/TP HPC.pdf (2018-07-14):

## Trabajo de Investigación: Integración de HPC en IOT

Adrian Radice and Facundo Sanabria

Universidad Nacional de La Matanza, Departamento de ingeniería e Investigaciones Tecnológicas, Florencio Varela 1903 - San Justo, Argentina {radiceadriann,facundosanabria}@gmail.com http://www.github.com/BitesellerSOA

Abstract. El objetivo del presente trabajo es investigar los beneficios de incorporar HPC en el proyecto de IOT MatulaRubik . Dicho proyecto tiene como desafío resolver un problema NP. Este problema es el puzzle Rubik 3x3x3, el cual se solucionara implementando el algoritmo no determinístico CFOP. CFOP varia de acuerdo cual se su cara de partida, por lo tanto para cualquier cubo se tienen 6 estados iniciales. El desafío es de 6 posibles caminos para llegar al estado final, quedarse con aquel que implique el menor uso del brazo lateral.

Keywords: HPC, IOT, Android, Rubik, Paralelismo, OpenCL

### 1 Introducción

MatulaRubik es un SE con el objetivo de resolver el Cubo Rubik de 3x3x3, en una primera instancia aplicando el algoritmo utilizado para competencias de velocidad CFOP, el cual obtiene un promedio entre 50 y 100 movimientos para resolver cualquier cubo. Este algoritmo pertenece a la familia de los llamados Layer by Layer, y se caracteriza por llevar a cualquier configuración del cubo a un estado particular, reduciendo siempre al problema a la misma solución. En pocas palabras mezcla aun mas el cubo para llevarlo a estados conocidos. CFOP es un algoritmo en donde un estado tienen distintas transiciones que nos llevan al estado final, siendo cada una finalmente un camino con distinta o igual cantidad de movimientos.
El objetivo de esta investigación, es reducir el tiempo en que MatulaRubik entrega la solución. MatulaRubik actualmente en su mecánica, tiene un retardo extra, la ubicación de las caras laterales en el correspondiente brazo para poder rotarlas. Se buscara mediante la implementación de HPC con OpenCL, encontrar la solución que reduce el retardo previamente descrito.

### 2 Desarrollo

Estudiando la mecánica de MatulaRubik se aprecia que el efectuar movimientos en las caras L, F, R, B pueden sumar un retardo, que no existe nunca al trabajarse

2 | Investigación: HPC y Rubik

con las caras U y D. Por ejemplo la secuencia de movimientos F, B’ implica, que luego de ejecutarse el primer movimiento, se sume un retardo temporal hasta que la cara B del cubo quede frente al brazo. Este retardo es el tiempo que implica retirar el brazo lateral, rotar el cubo hasta que B quede frente del brazo, y que el brazo lateral se ubique nuevamente en la posición de trabajo.
Enfrentar dicho problema implicaría dos caminos, cambiar la mecánica, o buscar una reducción en los movimientos de las caras problemáticas. En el desarrollo del trabajo optaremos por el segundo camino.
MatulaRubik en su estado actual aplica el algoritmo CFOP, el mismo presenta la particularidad que para una misma configuración del cubo de acuerdo a la cara que se tome como punto de partida devolverá una secuencia de movimientos totalmente distinto. Es decir, es como si se rotase lógicamente el cubo respecto de uno de sus ejes, lo que provoca que todas las piezas cambien de posición y orientación, resultando en un estado desordenado distinto y por lo tanto el algoritmo devolverá un conjunto de movimientos completamente distinto. Para lograr obtener la menor cantidad de movimientos posibles utilizando este algoritmo nos proponemos a ejecutar en forma paralela 6 hilos de CFOP, un hilo por cara del cubo.
En busca de no tener que modificar demasiado el código actualmente implementado, se busco una herramienta que implique una implementación sencilla y optima de paralelismo. La herramienta seleccionada fue Paralldroid. Paralldroid es un framework de desarrollo, que tiene como objetivo facilitar el trabajo de los desarrolladores de aplicaciones móviles ejecutadas sobre sistemas operativos Android, de acuerdo a lo mencionado en ”Performance Analysis of Paralldroid Generated Programs” [1]. El mismo añade un conjunto de anotaciones al lenguaje Java, basadas en las definidas por el estándar OpenCL, permitiendo al desarrollador usar un lenguaje de alto nivel, sin entrar en detalle de implementación de paralelismo, y delegandole la responsabilidad a Paralldroid de generar el programa paralelo, segun lo indicado en ”ParallDroid: A Framework for Parallelism in Android” [2]. Paralldroid puede ser descargado como plugin para eclipse, y solo es necesario instalarlo para que comience a funcionar[1].


Fig. 1. Resultado de la refactorización [3].

Investigación: HPC y Rubik | 3

Como se puede apreciar en la Figura 1 este framework, mediante el código Java con anotaciones, obtendrá un código nativo OpenCL, invocado desde nuestras clases. Es elemental el uso de NDK en cualquier App para poder hacer uso de este framework.

### 3 Distribución de operaciones

La particularidad de los hilos de trabajos propuestos, es que son independíentes entre si, cada uno trabaja con su propia matriz de estado del cubo, sin intervenir con los otros. Partiendo de que el resultado de ParallDroid es una implementación de OpenCL [1], cada hilo tendrá destinado un WorkGroup independíente. La primera ventaja de esta división, es que cada WorkGroup podrá ser ejecutado en una unidad de procesamiento distinta, si OpenCL lo considera [3], y como segunda ventaja es el escalado automático (asignación de WorkGroup a las unidades de procesamiento) que implementa OpenCL [3]. Esta ultima ventaja hace referencia, a que un mismo código, en un dispositivo de mayor cantidad de unidades de procesamiento que WorkGroups, en el mejor de los casos cada se asignara un WorkGroup por unidad de procesamiento, y en un dispositivo de menor cantidad, OpenCL simplemente terminaría ejecutando un conjunto de los WorkGroups en serie, en las unidades de procesamiento disponible.

### 4 Explicación Algoritmo

Nos basamos en el típico ejemplo de paralelismo del producto entre un escalar y un vector. Buscar 6 soluciones es isomórfico a esto ultimo, si entendemos al resultado de la operación como un conjunto de 6 elementos.

Pseudocódigo

@Parallel
public class SolverHPC_CFOP { private caras[];
private Solucion[];
@Kernel
private void Solver(CaraInicial){
//CALCULAMOS LA SOLUCION
Solucion [CaraInicial] <- CFOP(caraInicial); }
private Solucion getBest(){
//SE CALCULA LA MEJOR SOLUCION
return Solucion[bestSol];
}
}
public class Solver{
SendSol(){

4 | Investigación: HPC y Rubik
| SendArduino(SolverHPC_CFOP.getBest());
}
}

Según lo mencionado en ”Performance Analysis of Paralldroid Generated Programs” [1], ParallelDroid al refactorizar el código, agregaría el manejo de hilos, y nos abstrae de su desarrollo.

### 5 Pruebas que pueden realizarse

Para probar el rendimiento se propone, el desarrollo de un programa probador que mida el tiempo que le implica resolver 50 estados desordenados distintos del puzzle a a MatulaRubik con HPC y luego sin HPC. A partir de estos resultados debería realizarse el promedio para ambos casos y comparar cual obtiene el mejor tiempo.
También seria útil comprobar que el conjunto de movimientos resultados sean distintos dependiendo por que cara se comienza y si difieren mucho entre ellos.

### 6 Conclusión

La fortaleza de la solución propuesta en la investigación, es que permite una implementación de paralelismo sin demasiado esfuerzo de desarrollo. Se aprovecha el poder computacional provisto por el Hardware de los dispositivos móviles, para contrarrestar una deficiencia mecánica.
Extender la propuesta a cada uno de los distintos estados de CFOP en lugar de solamente los 6 iniciales seria computacionalmente intratable dado que CFOP es un algoritmo no determinístico, con una excesiva cantidad de estados posibles. Se compensaría los retrasos impuestos por la mecánica, con el tiempo de la búsqueda de mejor solución.

References

1. A. Acosta and F. Almeida, ”Performance Analysis of Paralldroid Generated Pro-
| grams” 2014 22nd Euromicro International Conference on Parallel, Distributed, and Network-Based Processing, Torino, 2014, pp. 60-67.
2. Vicente Blanco, ”ParallDroid: A Framework for Parallelism in Android”.
3. Aaftab Munshi, ”The OpenCL Specification” Khronos OpenCL Working Group,
| Revision 2015.

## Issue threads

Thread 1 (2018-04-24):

App: Obtener colores con la cámara, usando OpenCV.

adrianRadice, 2018-04-24:

adrianRadice, 2018-04-24:
### Ideas:
- Se puede realizar un bucle en el que se filtre por color y obtener por cada iteración la posición de un color en particular. Esto es por cara a analizar.

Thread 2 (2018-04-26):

Mejora: Problemas de luz

adrianRadice, 2018-04-26:
Se puede usar un LDR para capturar la luz ambiente y de esta forma poder acomodar los filtros aplicados a la camara

adrianRadice, 2018-04-26:
Tambien podria ser iluminada cada cara por un par de leds

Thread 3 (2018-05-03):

Torre Pinza

adrianRadice, 2018-05-03:
# Torre X4.

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

adrianRadice, 2018-05-07:
Probando Retroceso, configuramos un L293D  (Puente H X2) para el control del giro del M-DC, utilizando 5V suministrado por una ATX al (PIN 8), y usando dos salidas digitales del ARDUINO para Control.
[Video](https://drive.google.com/file/d/1c4hVl0s1xOgOLpFpAcy6ZB6e04y_enDS/view?usp=sharing)

adrianRadice, 2018-06-27:
Estructura regulable, y que permite armarse en 15 min para poder ser facilmente transportable
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

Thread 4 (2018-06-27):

App Secuencia Comunicación Arduino

adrianRadice, 2018-06-27:
### PSEUDO-CODIGO
1.   La App verifica si existe el Arduino
1.1  La App envía un mensaje a la Dirección IP del Arduino
1.2. La app Espera respuesta del Arduino por un intervalo de tiempo determinado
1.3. El Arduino ante la solicitud del celular puede
1.3.a No reponder
1.3.a.1 Se vence el plazo de tiempo en la app y emite un mensaje decir que Arduino no reponde
1.3.b Estoy Ocupado
1.3.b.1 La app informa el estado del Arduino.
1.3.c Estoy disponible
2. Si La app determina la disponibilidad del Arduino, verifica tener el cubo frente a su cámara.
2.1 Si la respuesta anterior es negativa solicita que se coloque un cubo
2.2 Si la respuesta anterior es positiva escanea la primer cara
2.3 La app Envia un post a Arduino indicando que mueva el motor de abajo y superior en sentido horario
2.4 Arduino ejecuta el movimiento y informa a la app
2.5 La app escanea la cara
se repite 3 veces la secuencia del 2.4 al 2.5
3. La app notifica que se mueva el motor lateral mediante un post para escanear la cara inf
3.1 Arduino recibe la solicitud ejecuta la convinación de movimiento motor lateral y luego inferior y superior para que la cara inferior quede frente la camara
3.1 La app escanea la cara
4. La app notifica que se mueva el motor inf y sup para que la cara sus quede frente a la cámara
4.1 Arduino recibe la solicitud ejecuta el movimiento
4.2 La app escanea la cara
5. La app Aplica el algoritmo para resolver, mientras tanto Arduino espera el post de la app indicando la disponibilidad de la solución para poder descargarla y aplicarla.
6. La app espera que Arduino indique que termino de aplicar la secuencia de movimientos y notifica a la aplicación que finalizo.

**APARTIR DE PASO 5 NO ES NECESARIO EL CELULAR EN LA BASE DE LA MAQUINA**

### LA COMUNICACION ES MEDIANTE INTERCAMBIO DE PAQUETES JSON
Recordar incluir libreria ArduinoJson

adrianRadice, 2018-06-27:
## HEADER JSON PETICION POST
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

adrianRadice, 2018-06-27:
No

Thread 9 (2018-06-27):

Ideas HPC

adrianRadice, 2018-06-27:
Tiremos ideas para HPC

adrianRadice, 2018-06-27:
# Escaneo Caras
No tiene sentido porque para obtener colores es simultaneo porque uno aplca 6 mascaras una por cara del cubos y al mismo tiempo se aplica sobre el espacio de color hsv y retorna por lo tanto los colores, tal vez se puede la escritura del color sobre el arreglo de arrays de psociones pero para mi no sive

adrianRadice, 2018-06-27:
# Desplazamientos
Esta la veo linda porque penzemos que pasa cuando rotas una cara, supongamos que rotamos la de arriba sentido horario
En nuestra matriz o arreglo de arrays se efectuan un par de intercambios pero notar que se pueden paralelizar los intercambios en tres grupos, osea basicamente cuando se. Rota se remplazan tres rondas. Pongo un ejemplo mejor jeje
R1 R2 R3
A1 A2 A3
N1 N3 N3
V1 V2 V3
Cada letra indica un color y en numero una arista/esquina
Si rotas la cara superior obtenes
V1 V2 V3
R1 R2 R3
A1 A2 A3
N1 N2 N3

Los tres grupos que planteo serian las columnas , ya que cada columna se puede obtener de forma independiente a las otras.

adrianRadice, 2018-06-27:
# Bactraking fridrich
El titulo lo explica todo jejeje

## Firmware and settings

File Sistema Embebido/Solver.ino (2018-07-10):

#include <Cubo.h>
#include <DRV8825.h>
#include <SPI.h>
#include <Ethernet.h>
#include <ArduinoJson.h>  

byte mac[] = {0x98, 0x4F, 0xEE, 0x01, 0x11, 0x90 };    
IPAddress ip(192,168,1,50);
EthernetServer server(8080);
EthernetClient client;
const size_t MAX_BODY_SIZE = 200;      
String respuesta = "";

const int fwdPin=52;
const int revPin=53;
const int pasos=200;
const int steps=100;
const int grados120=100;
const int grados90=50;
const int grados45=25;
const int tiempoLectora=10;
const int pausa=5000;

DRV8825 arriba(40,39,28);
DRV8825 abajo(45,44,42);
DRV8825 lateral(50,49,47);

Cubo cubo(arriba, abajo, lateral, fwdPin, revPin, pasos, steps, grados120, grados90, grados45, tiempoLectora, pausa);

void setup() {
  Serial.begin(9600);
  pinMode(3, OUTPUT);
  Ethernet.begin(mac, ip);
  server.begin();
  delay(100);
}


void loop() 
{
  client = server.available();
  if (client) 
  {
    Serial.print("Cliente Conectado...");
    boolean currentLineIsBlank = true;
    respuesta = "";
    while (client.connected()) 
    {
      if (client.available())
      {
        char c = client.read();
        respuesta += c;
        if (c == '\n' && currentLineIsBlank && respuesta.startsWith("POST")) 
        {
          analizarPost();
          break;
        }
        if (c == '\n')
        {
          currentLineIsBlank = true;
        } 
        else if (c != '\r')
        {
          currentLineIsBlank = false;
        }
      }
    }
   // delay(1);
    client.stop();
  }
}
bool analizarPost()
{
  char body_post[MAX_BODY_SIZE]="";
  char estado_led[10]="";
  String respuesta_aux = respuesta.substring(respuesta.indexOf("/led/"));
  int num_pin = '3';
  if(leerBodyPost(respuesta,body_post)==false)
  {
     Serial.println("Error al leer el campo Body");
     enviarHttpResponse_BadRequest(client);
     return false;
  }
  if(num_pin=='3')
  {
     if(parserBodyPost(body_post,estado_led)==false)
     {
        Serial.println("Error al realizar el parser");
        enviarHttpResponse_BadRequest(client);
        return false;
     }
     else
     {
       cubo.Mover(estado_led[0]);
      
       Serial.print("Moviendo: ");
       Serial.println(estado_led);
       delay(1000);
       enviarHttpResponse_OK(client);
       return true;
     }
     
  }
  Serial.println("Numero de Pin Incorrecto..");
  enviarHttpResponse_BadRequest(client);

  return false;
}
bool leerBodyPost(String respuesta,char * body_post)
{
  int data_length=-1;
  int i=0;
  char c;
  String body_tam = respuesta.substring(respuesta.indexOf("Content-Length:") + 15);
  body_tam.trim();
  data_length = 11;
  if(data_length>MAX_BODY_SIZE)
  {
    Serial.println("ERROR MAX_BODY_SIZE NO ES LO SUFICIENTEMENTE GRANDE PARA ALMACENAR EL CONTENIDO DE BODY");
    return false; 
  }
  while(i < data_length)
  {
    c = client.read();
    body_post[i] =c;
    i++;
  }
  //Serial.println(body_post);
  return true;
}
bool parserBodyPost(char * content, char * estado)
{
  const size_t BUFFER_SIZE = JSON_OBJECT_SIZE(1); 
  
  DynamicJsonBuffer jsonBuffer(BUFFER_SIZE);
  JsonObject& root = jsonBuffer.parseObject(content);
  if (!root.success()) 
  {
    Serial.println("JSON parsing failed!");
    return false;
  }
  strcpy(estado, root["MOV"]);
  //Serial.println("estado:");
  //Serial.println(estado);
  return true;
}


void enviarHttpResponse_OK(EthernetClient& client) 
{
  client.println("HTTP/1.1 200 OK");
  //client.println("Content-Type: application/json");
  client.println("Connection: close");
  client.println();
}

void enviarHttpResponse_BadRequest(EthernetClient& client) 
{
  client.println("HTTP/1.1 400 BAD REQUEST");
  client.println("Content-Type: text/html");
  client.println("Connection: close");
  client.println();
  client.println("<!DOCTYPE HTML>");
  client.println("<html> <body>");
  client.println("BAD REQUEST"); 
  client.println("</body> </html>");
  client.println();
}

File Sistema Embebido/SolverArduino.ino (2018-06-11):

#define R 'R'  // CARACTER QUE REPRESENTA EN LA SOLUCION UN MOVIMIENTO DE LA CARA DERECHA SENTIDO HORARIO
#define L 'L'  // CARACTER QUE REPRESENTA EN LA SOLUCION UN MOVIMIENTO DE LA CARA IZQUIERDA SENTIDO HORARIO
#define D 'D'  // CARACTER QUE REPRESENTA EN LA SOLUCION UN MOVIMIENTO DE LA CARA INFERIOR SENTIDO HORARIO
#define U 'U'  // CARACTER QUE REPRESENTA EN LA SOLUCION UN MOVIMIENTO DE LA CARA SUPERIOR SENTIDO HORARIO
#define B 'B'  // CARACTER QUE REPRESENTA EN LA SOLUCION UN MOVIMIENTO DE LA CARA TRASERA SENTIDO HORARIO
#define FC 'F' // CARACTER QUE REPRESENTA EN LA SOLUCION UN MOVIMIENTO DE LA CARA FRONTAL SENTIDO HORARIO
#define RA 'X' // CARACTER QUE REPRESENTA EN LA SOLUCION UN MOVIMIENTO DE LA CARA DERECHA SENTIDO ANTI-HORARIO
#define LA 'Y' // CARACTER QUE REPRESENTA EN LA SOLUCION UN MOVIMIENTO DE LA CARA IZQUIERDA SENTIDO ANTI-HORARIO
#define DA 'Z' // CARACTER QUE REPRESENTA EN LA SOLUCION UN MOVIMIENTO DE LA CARA INFERIOR SENTIDO ANTI-HORARIO
#define UA 'V' // CARACTER QUE REPRESENTA EN LA SOLUCION UN MOVIMIENTO DE LA CARA SUPERIOR SENTIDO ANTI-HORARIO
#define BA 'W' // CARACTER QUE REPRESENTA EN LA SOLUCION UN MOVIMIENTO DE LA CARA TRASERA SENTIDO ANTI-HORARIO
#define FA 'N' // CARACTER QUE REPRESENTA EN LA SOLUCION UN MOVIMIENTO DE LA CARA FRONTAL SENTIDO ANTI-HORARIO

#include <SPI.h>
#include <Ethernet.h>
byte mac[] = {
  0xDE, 0xAD, 0xBE, 0xEF, 0xFE, 0xED
};
IPAddress ip(192, 168, 1, 177);
EthernetServer server(80);

// L Y R SERAN MOVIDOS POR LOS BRAZOS INFERIOR Y SUPERIOR EN FORMA RELATIVA A COMO SE COLOQUE EL CUBO
// U B F D SERAN MOVIDOS POR EL BRAZO LATERAL 
char posBrazoLateral='N';  // VARIABLE GLOBAL QUE ALMACENA LA POSICION ACTUAL DEL BRAZO LATERAL

void setup() {
}

void loop() {

}

//RUTINA PARA MOVER EN SENTIDO HORARIO LA CARA DERECHA DEL CUBO
void r()
{
}
//RUTINA PARA MOVER EN SENTIDO ANTI-HORARIO LA CARA DERECHA DEL CUBO
void rA()
{
}
//RUTINA PARA MOVER EN SENTIDO HORARIO LA CARA IZQUIERDA DEL CUBO
void l()
{
}
//RUTINA PARA MOVER EN SENTIDO ANTI-HORARIO LA CARA IZQUIERDA DEL CUBO
void lA()
{
}
//RUTINA PARA MOVER EN SENTIDO HORARIO LA CARA INFERIOR DEL CUBO
void d()
{
   //INDICO POS ACTUAL DEL BRAZO LATERAL
   posBrazoLateral = D;
}
//RUTINA PARA MOVER EN SENTIDO ANTI-HORARIO LA CARA INFERIOR DEL CUBO
void dA()
{
   //INDICO POS ACTUAL DEL BRAZO LATERAL
   posBrazoLateral = D;
}
//RUTINA PARA MOVER EN SENTIDO HORARIO LA CARA SUPERIOR DEL CUBO
void u()
{
   //INDICO POS ACTUAL DEL BRAZO LATERAL
   posBrazoLateral = U;
}
//RUTINA PARA MOVER EN SENTIDO ANTI-HORARIO LA CARA SUPERIOR DEL CUBO
void uA()
{
   //INDICO POS ACTUAL DEL BRAZO LATERAL
   posBrazoLateral = U;
}
//RUTINA PARA MOVER EN SENTIDO HORARIO LA CARA TRASERA DEL CUBO
void b()
{
   //INDICO POS ACTUAL DEL BRAZO LATERAL
   posBrazoLateral = B;
}
//RUTINA PARA MOVER EN SENTIDO ANTI-HORARIO LA CARA TRASERA DEL CUBO
void bA()
{
   //INDICO POS ACTUAL DEL BRAZO LATERAL
   posBrazoLateral = B;
}
//RUTINA PARA MOVER EN SENTIDO HORARIO LA CARA FRONTAL DEL CUBO
void f()
{
   //INDICO POS ACTUAL DEL BRAZO LATERAL
   posBrazoLateral = FC;
}
//RUTINA PARA MOVER EN SENTIDO ANTI-HORARIO LA CARA FRONTAL DEL CUBO
void fA()
{
   //INDICO POS ACTUAL DEL BRAZO LATERAL
   posBrazoLateral = FC;
}

// TRADUCE LA LECTURA DE LA SOLUCION EN LLAMADA A LAS FUNCIONES PARA LOS MOVIMIENTOS
void mover(char m){
  switch(m){
    case R:
      r();
    break;
    case RA:
      rA();
    break;
    case L:
      l();
    break;
    case LA:
      lA();
    break;
    case U:
      u();
    break;
    case UA:
      uA();
    break;
    case D:
      d();
    break;
    case DA:
      dA();
    break;
    case B:
      b();
    break;
    case BA:
      bA();
    break;
    case FC:
      f();
    break;
    case FA:
      fA();
    break;
  }
}



bool existeSolucion()
{
  
}

bool leerPulsador()
{
  
}

void descargarSolucion()
{
  
}

void prepararBrazosResolver()
{
  
}

void entregarCubo()
{
  
}

void procesarSolucion()
{
  
}

void prepararRecepcion()
{
  
}

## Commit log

2018-04-26 Estructurando directorios indicados por la catedra
    Se implementan los directorios indicados en la ppt de git. Los mismos contienen los correspondientes "LEAME.txt"
2018-06-05 se empieza con el algoritmode la cruz
2018-06-06 se reorganiza la cruz
2018-06-06 se agrega el algoritmo para los blancos abajo en la cruz
2018-06-11 Definimos Constantes Movimientos
    Definimos un grupo de constantes char que deben coincidir con los almacenados en la app android, y que representan los movimientos que nos seran enviados desde el celular
2018-06-11 Definimos firmas de las func para mov de los mot
    Definimos las firmas de las funciones que tiene las rutinas para poder mover las caras del cubo, los nombres hacen referencia a la cara y si finalizan en A indica que el sentido es antihorario. Tambi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
2018-06-11 Add Funcion mover
    Agregamos la función que mapea carácter leído de la solución con llamado a función
2018-06-28 add diseño
    [MatulaCircuit.fzz]
